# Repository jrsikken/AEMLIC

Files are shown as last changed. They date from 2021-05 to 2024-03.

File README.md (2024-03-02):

The AEMLIC is a 15x20mm board with the AEM10941 Solar Harvesting IC from E-peas. It efficiently converts solar panel energy into LIC charge, it even works with indoor light. It has one regulated output that is enabled when the LIC has sufficient charge, and a low voltage warning that informs the user of impending shutdown when the LIC runs low. It easily integrates in other projects because of the castellated via's, and when soldered onto 0.1' pitch headers it fits in a bread board.

The .xlsx contains the AEMLIC PCB specification, Bill of Materials, the placement drawing, and the XY positions file 
The .zip files contains the PCB gerber files
The .sch and .pcb are Eagle Design files

I am selling this board here:
https://www.tindie.com/products/jaspersikken/solar-harvesting-into-lithium-ion-capacitor/



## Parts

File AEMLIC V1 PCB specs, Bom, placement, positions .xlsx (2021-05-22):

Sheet: PCB Specification
Your PCB Specification
PCB Quantity | 50, 100 pcs
Layer | 2layer
PCB Thickness | 1.6mm
Dimensions | 20x15mm
Castellated Hole | yes, on 2 sides
PCB Color | white
Surface Finish | HASL Lead Free
Copper Weight | 1oz
Text Color | black
Different Design | 1
Remark: Please no v-scoring on castellated holes

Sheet: BOM
AEMLIC
# | Reference | QTY | Value | Package | Manufacturer | Manufacturer Part number | Description | SMD | THT | Original | Elecrow PN | Note | Voltage | Dielectric | Tolerance
1 | C1, C3, C4 | 3 | 10uF | C0603 | Generic part | Generic part | Non-polarized capacitor | 6 |  | N |  |  | 10V | X5R | 20%
2 | C2 | 1 | 22uF 10V | C0603 | Generic part | Generic part | Non-polarized capacitor | 2 |  | N |  |  | 10V | X5R | 20%
3 | L2 | 1 | 10uH | L0603 | TDK Corporation | MLZ1608M100WT000 | Inductor | 2 |  | Y
4 | L1 | 1 | 10uH-0.55A | 3.9X3.9mm | COILCRAFT | LPS4012-103MRB | Inductor | 2 |  | Y
5 | R1 | 1 | 2.61M | R0402 | Generic part | Generic part | Resistor | 2 |  | N |  |  |  |  | 1%
6 | R7, R8 | 2 | 1M | R0402 | Generic part | Generic part | Resistor | 4 |  | N |  |  |  |  | 5%
7 | R4 | 1 | 5.9M | R0402 | Generic part | Generic part | Resistor | 2 |  | N |  |  |  |  | 1%
8 | R5 | 1 | 453k | R0402 | Generic part | Generic part | Resistor | 2 |  | N |  |  |  |  | 1%
9 | R6 | 1 | 549k | R0402 | Generic part | Generic part | Resistor | 2 |  | N |  |  |  |  | 1%
10 | R2 | 1 | 1.21M | R0402 | Generic part | Generic part | Resistor | 2 |  | N |  |  |  |  | 1%
11 | R3 | 1 | 150k | R0402 | Generic part | Generic part | Resistor | 2 |  | N |  |  |  |  | 1%
12 | Q1 | 1 | DMG1012UW | SOT323 | Diodes | DMG1012UW-7 | Mosfet N channel | 3 |  | Y
13 | IC1 | 1 | AEM10941 | QFN50P505X505X90-28 | E-peas | AEM10941 | Ambient Energy Manager from e-peas | 28 |  | Y, supplied by customer, shipped 26-03-2021 to Elecrow JVGLEXP0685376109
 |  |  |  |  |  |  | total： | 59 | 0

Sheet: Position File
Designator | Footprint | Center-X(mm) | Center-Y(mm) | Layer | Rotation
C1 | C0603 | 6.23 | 7.52 | top | 90
C2 | C0603 | 6 | 3 | top | 180
C3 | C0603 | 12 | 3 | top | 0
C4 | C0603 | 15.34 | 10.13 | top | 90
IC1 | QFN50P505X505X90-28 | 10.7 | 7.3 | top | 90
L1 | LPS4012 | 3.13 | 7.22 | top | 270
L2 | L0603 | 9 | 3 | top | 180
Q1 | SOT323 | 17.95 | 5.5 | top | 270
R1 | R0402 | 7.42 | 11.26 | top | 180
R2 | R0402 | 5.62 | 11.26 | top | 180
R3 | R0402 | 3.82 | 11.26 | top | 180
R4 | R0402 | 2.02 | 11.26 | top | 180
R5 | R0402 | 15.4 | 6 | top | 90
R6 | R0402 | 15.4 | 7.8 | top | 90
R7 | R0402 | 17.52 | 7.14 | top | 180
R8 | R0402 | 18.9 | 7.61 | top | 90

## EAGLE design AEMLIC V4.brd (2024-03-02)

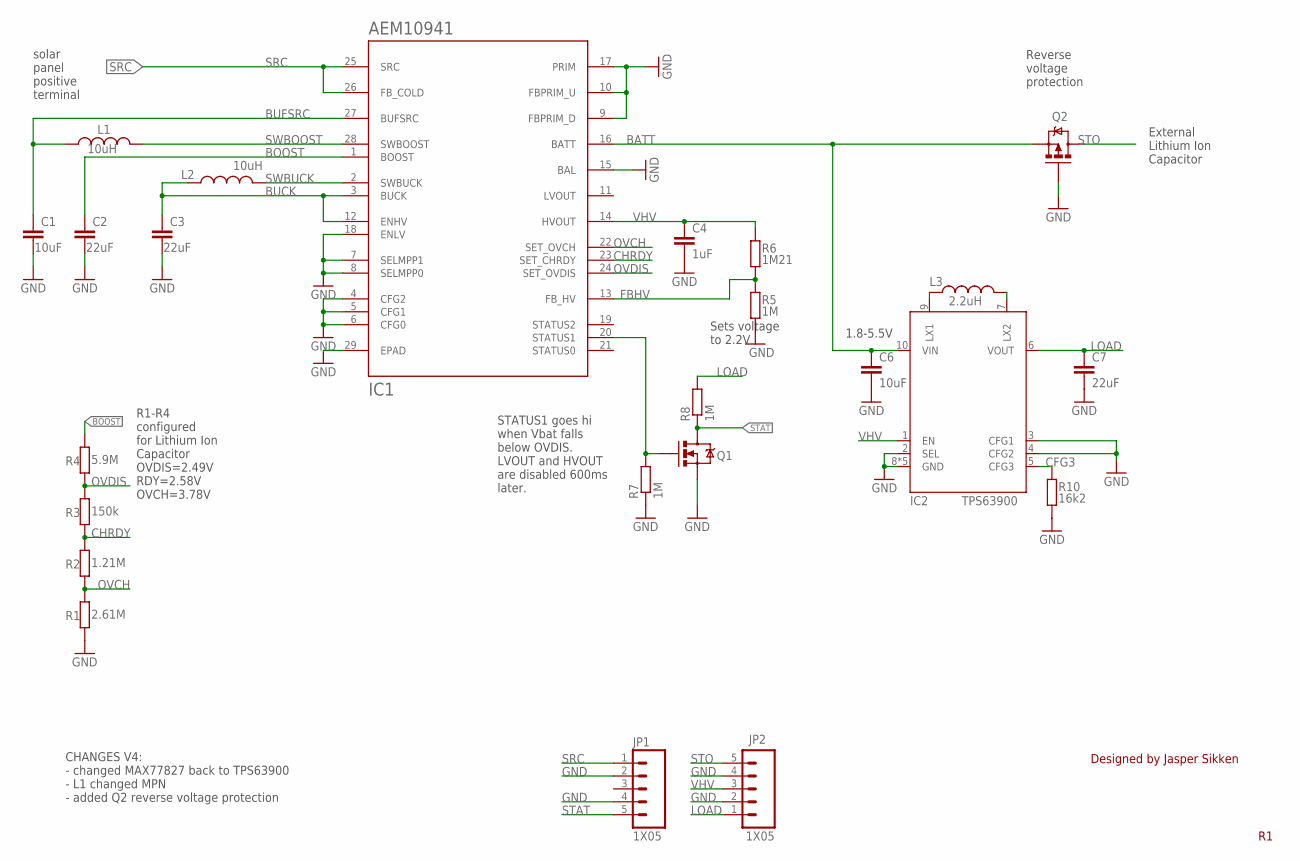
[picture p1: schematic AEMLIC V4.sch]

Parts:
C1: 10uF; C0603; MPN 1049P
C2: 22uF; C0603; MPN CGA5L1X7S1A226M160AC
C3: 22uF; C0603; MPN 1049P
C4: 1uF; C0603
C6: 10uF; C0603
C7: 22uF; C0603
IC1: AEM10941; QFN50P505X505X90-28
IC2: TPS63900; WSON10
JP1, JP2: 1X05; 1X05_2.54MM_ROUND_NOSILK
L1: 10uH; L_3225MM
L2: 10uH; L0603; MPN CK2125100M-T
L3: 2.2uH; L_1008_[2520]
Q1: DMG1012UW; SOT323
Q2: DMP2160UW; SOT323
R1: 2.61M; R0402
R2: 1.21M; R0402
R3: 150k; R0402
R4: 5.9M; R0402
R5, R7, R8: 1M; R0402
R6: 1M21; R0402
R10: 16k2; R0402

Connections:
BATT: C6.1, IC1.16 (BATT), IC2.10 (VIN), Q2.2 (S)
BOOST: C2.1, IC1.1 (BOOST), R4.2
BUCK: C3.1, IC1.3 (BUCK), IC1.12 (ENHV), L2.1
BUFSRC: C1.1, IC1.27 (BUFSRC), L1.1
CFG3: IC2.5 (CFG3), R10.1
CHRDY: IC1.23 (SET_CHRDY), R2.2, R3.1
FBHV: IC1.13 (FB_HV), R5.2, R6.1
GND: C1.2, C2.2, C3.2, C4.2, C6.2, C7.2, IC1.4 (CFG2), IC1.5 (CFG1), IC1.6 (CFG0), IC1.7 (SELMPP1), IC1.8 (SELMPP0), IC1.9 (FBPRIM_D), IC1.10 (FBPRIM_U), IC1.15 (BAL), IC1.17 (PRIM), IC1.18 (ENLV), IC1.29 (EPAD), IC2.2 (SEL), IC2.3 (CFG1), IC2.4 (CFG2), IC2.8 (GND), IC2.29 (GND), IC2.P$2 (GND), IC2.P$4 (GND), IC2.P$5 (GND), JP1.2, JP1.4, JP2.2, JP2.4, Q1.2 (S), Q2.1 (G), R1.1, R5.1, R7.1, R10.2
LOAD: C7.1, IC2.6 (VOUT), JP2.1, R8.2
unnamed: IC2.9 (LX1), L3.1
unnamed: IC2.7 (LX2), L3.2
OVCH: IC1.22 (SET_OVCH), R1.2, R2.1
OVDIS: IC1.24 (SET_OVDIS), R3.2, R4.1
SRC: IC1.25 (SRC), IC1.26 (FB_COLD), JP1.1
STAT: JP1.5, Q1.3 (D), R8.1
STATUS1: IC1.20 (STATUS1), Q1.1 (G), R7.2
STO: JP2.5, Q2.3 (D)
SWBOOST: IC1.28 (SWBOOST), L1.2
SWBUCK: IC1.2 (SWBUCK), L2.2
VHV: C4.1, IC1.14 (HVOUT), IC2.1 (EN), JP2.3, R6.2

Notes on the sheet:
Designed by Jasper Sikken
solar panel positive terminal
1.8-5.5V
STATUS1 goes hi when Vbat falls below OVDIS. LVOUT and HVOUT are disabled 600ms later.
Sets voltage to 2.2V
R1-R4 configured for Lithium Ion Capacitor OVDIS=2.49V RDY=2.58V OVCH=3.78V
External Lithium Ion Capacitor
Reverse voltage protection
CHANGES V4: - changed MAX77827 back to TPS63900 - L1 changed MPN - added Q2 reverse voltage protection

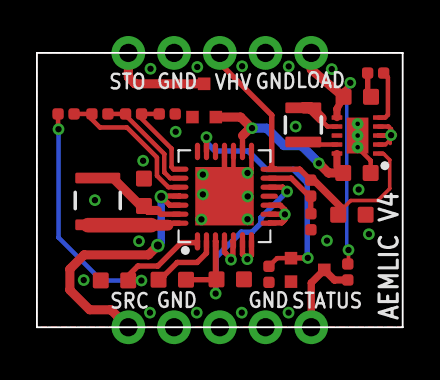
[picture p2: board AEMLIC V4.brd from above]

Board: 2 copper layers, 20.3 x 15.2 mm, 24 parts (0 on the bottom side), 20 nets.

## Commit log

2021-05-22 Add files via upload
    PCB specification, Bill of Materials, placement drawing and XY positions file
    [AEMLIC V1 PCB specs, Bom, placement, positions .xlsx]
2021-05-22 Add files via upload
    AEMLIC V1 Gerber files
2021-05-22 Add files via upload
    AEMLIC eagle design files
    [AEMLIC-V1.brd, AEMLIC-V1.sch]
